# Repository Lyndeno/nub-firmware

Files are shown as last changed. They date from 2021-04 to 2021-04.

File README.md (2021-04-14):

# nub-firmware

Firmware for NUB(Nodal Hub), a long range mesh messaging system. Capstone Project for Electrical Engineering at the University of Alberta.

## Frame Format

### NUB to NUB

| TAG | Message Type | Size of Path | Path | Data Size | Data |
| --- | --- | --- | ---- | --- | ---- |
| ```0x02``` | 1 Byte | 1 Byte | Variable | 2 Bytes | ```Data Size``` Bytes |

### Passing through ATmega

| TAG | Data Len | Message Type | Data Size | Data |
| --- | --- | --- | ---- | --- |
| ```0x02``` | 1 Byte | 1 Byte | 2 Bytes | ```Data Size``` bytes |

### Message Types

| Message Type Byte | Message |
| --- | --- |
| 0x01 | Text Messages |
| 0x02 | Connected/Disconnected phone |
| 0x03 | Adjust NUB Mesh |
| 0x04 | Message Acknowledgement |

## To-Do

- [x] Access point (mostly done)
- [x] Communications with Android app
- [x] UART communication between MCU and ESP8266
- [x] UART communication between MCU and transceiver
- [ ] ~~Power management (Sleep, power button)~~ batteries not allowed for project anymore
- [ ] Status LEDs
- [ ] Serial output? (For debugging)

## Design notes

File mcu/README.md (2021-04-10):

# MCU

The code in this folder is for the main MCU in the NUB. We are using the Atmel ATmega328PB MCU to handle relaying messages between other NUBs and connected Android devices.

## How to Build

This code is developed using Microchip MPLabX with the XC8 compiler. This can be installed on Windows or Linux. If you're using Arch Linux:

``` bash
$ paru -S --needed microchip-mplabx-bin microchip-mplabxc8-bin # Assuming you use paru as an AUR helper
```

You then should be able to just open up this project and compile.

## Design Goals

There are several design goals we want to meet for the best performance:

- [x] Transfer data without variables when possible. We want to ensure there is enough memory for buffers.
- [x] We will have one buffer for each direction of transmission for each connected device.
- [ ] Achieve a 19200 or 115200 baud rate with the long-range transceiver.
- [ ] Achieve a 115200 baud rate with the ESP8266.
- [ ] Protocol to decide when to process what data.
- [ ] Choose a CPU frequency that works at 3.3V, while also achieving the baud rates listed above.
- [x] Buffer sizes that fit in memory, 256 or 512 bytes should be more than enough.

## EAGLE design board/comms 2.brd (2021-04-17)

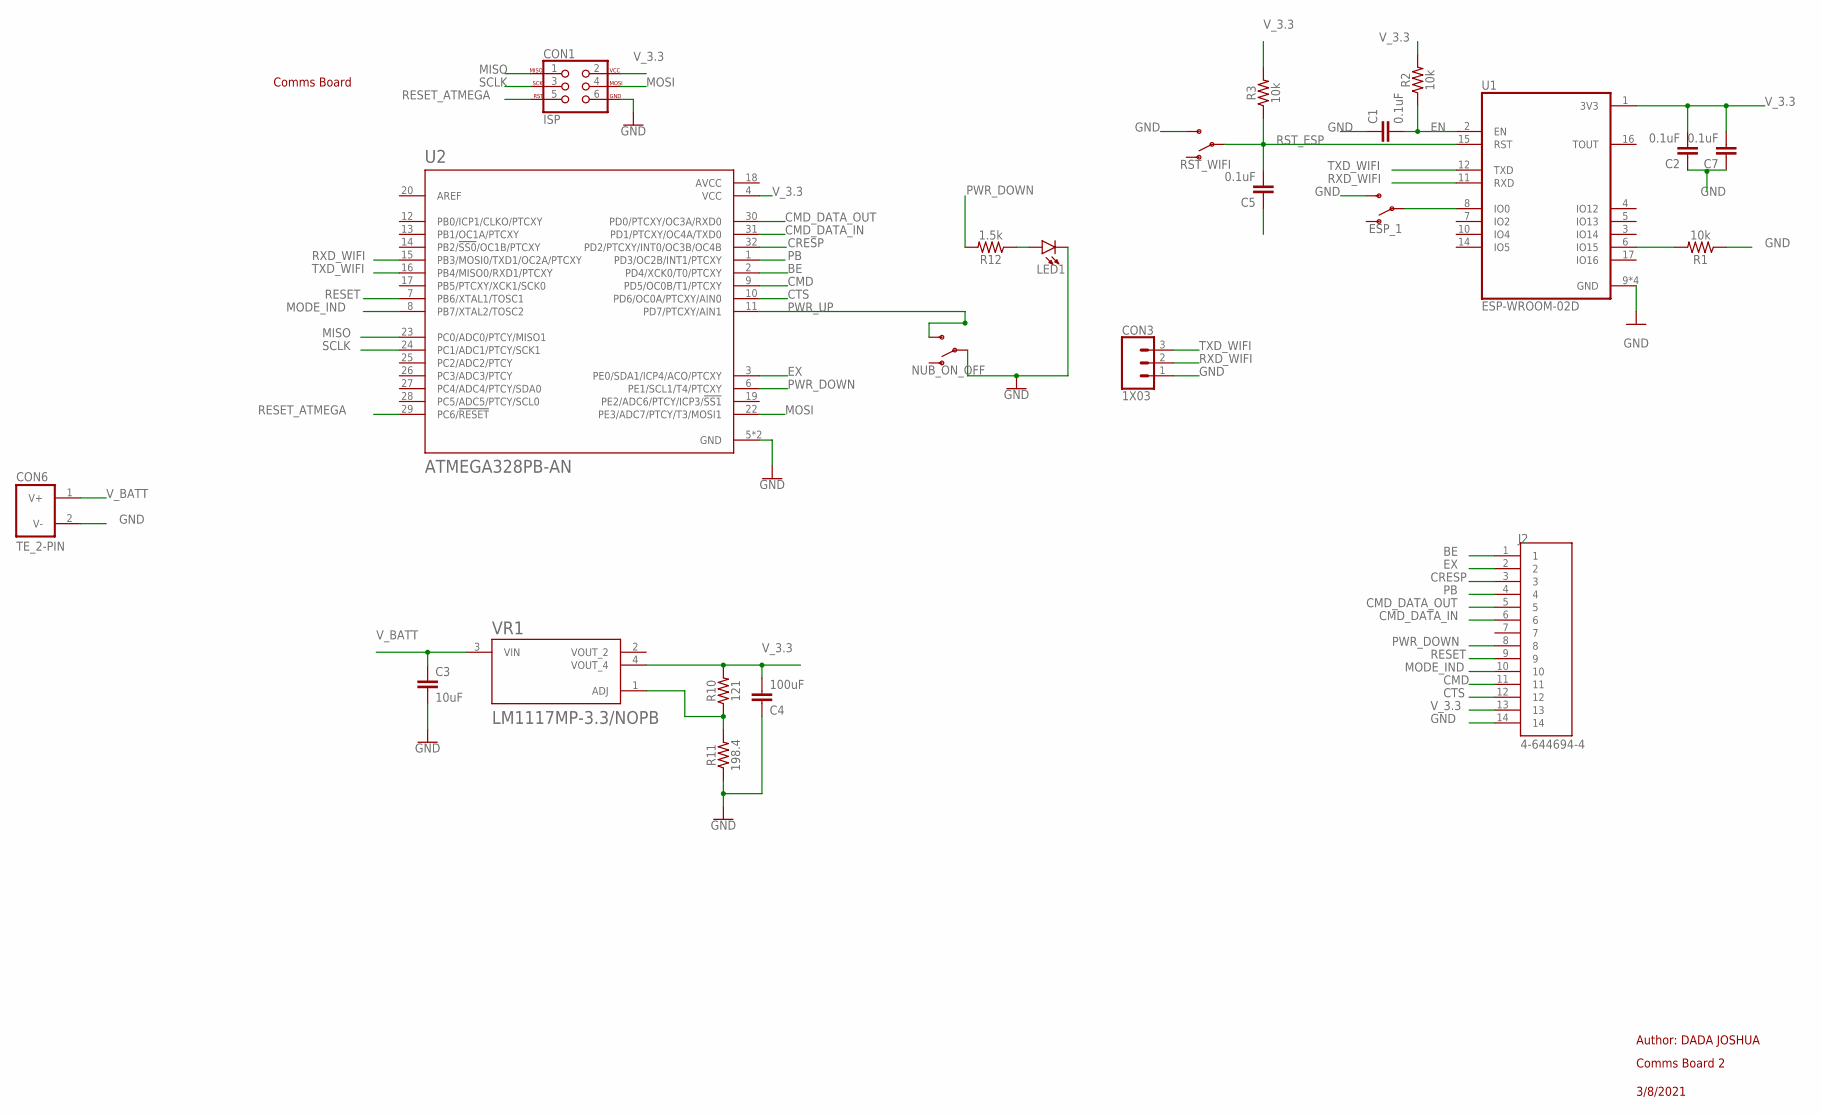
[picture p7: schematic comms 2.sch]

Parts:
C1, C2, C5, C7: 0.1uF; 1210
C3: 10uF; 1210
C4: 100uF; 1210
CON1: ISP; ISP_CONNECTOR
CON3: 1X03
CON6: TE_2-PIN
ESP_1: SWITCH_SPDT
J2: 4-644694-4; TE_4-644694-4
LED1: LED_THROUGH-HOLE
NUB_ON_OFF: SWITCH_SPDT
R1, R2, R3: 10k; 1210
R10: 121; 1210
R11: 198.4; 1210
R12: 1.5k; 1210
RST_WIFI: SWITCH_SPDT
U1: ESP-WROOM-02D; MODULE_ESP-WROOM-02D
U2: ATMEGA328PB-AN; QFP80P900X900X120-32N
VR1: LM1117MP-3.3/NOPB; VREG_LM1117MP-3.3/NOPB

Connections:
AVCC: U2.18 (AVCC)
BE: J2.1, U2.2 (PD4/XCK0/T0/PTCXY)
CMD: J2.11, U2.9 (PD5/OC0B/T1/PTCXY)
CMD_DATA_IN: J2.6, U2.31 (PD1/PTCXY/OC4A/TXD0)
CMD_DATA_OUT: J2.5, U2.30 (PD0/PTCXY/OC3A/RXD0)
CRESP: J2.3, U2.32 (PD2/PTCXY/INT0/OC3B/OC4B)
CTS: J2.12, U2.10 (PD6/OC0A/PTCXY/AIN0)
EN: C1.2, R2.1, U1.2 (EN)
EX: J2.2, U2.3 (PE0/SDA1/ICP4/ACO/PTCXY)
GND: C1.1, C2.1, C3.2, C4.1, C5.1, C7.1, CON1.6, CON3.1, CON6.2 (V-), ESP_1.3 (S), J2.14, LED1.C, NUB_ON_OFF.2, R1.1, R11.1, RST_WIFI.3 (S), U1.9 (GND), U1.13 (GND), U1.18 (GND), U1.19 (GND), U2.5 (GND), U2.21 (GND)
MISO: CON1.1, U2.23 (PC0/ADC0/PTCY/MISO1)
MODE_IND: J2.10, U2.8 (PB7/XTAL2/TOSC2)
MOSI: CON1.4, U2.22 (PE3/ADC7/PTCY/T3/MOSI1)
unnamed: R10.1, R11.2, VR1.1 (ADJ)
unnamed: R1.2, U1.6 (IO15)
unnamed: LED1.A, R12.1
unnamed: ESP_1.2, U1.8 (IO0)
PB: J2.4, U2.1 (PD3/OC2B/INT1/PTCXY)
PWR_DOWN: J2.8, R12.2, U2.6 (PE1/SCL1/T4/PTCXY)
PWR_UP: NUB_ON_OFF.3 (S), U2.11 (PD7/PTCXY/AIN1)
RESET: J2.9, U2.7 (PB6/XTAL1/TOSC1)
RESET_ATMEGA: CON1.5, U2.29 (PC6/!RESET)
RST_ESP: C5.2, R3.1, RST_WIFI.2, U1.15 (RST)
RXD_WIFI: CON3.2, U1.11 (RXD), U2.15 (PB3/MOSI0/TXD1/OC2A/PTCXY)
SCLK: CON1.3, U2.24 (PC1/ADC1/PTCY/SCK1)
TXD_WIFI: CON3.3, U1.12 (TXD), U2.16 (PB4/MISO0/RXD1/PTCXY)
V_3.3: C2.2, C4.2, C7.2, CON1.2, J2.13, R2.2, R3.2, R10.2, U1.1 (3V3), U2.4 (VCC), VR1.4 (VOUT_4)
V_BATT: C3.1, CON6.1 (V+), VR1.3 (VIN)

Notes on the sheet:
Comms Board
Author: DADA JOSHUA
Comms Board 2
3/8/2021

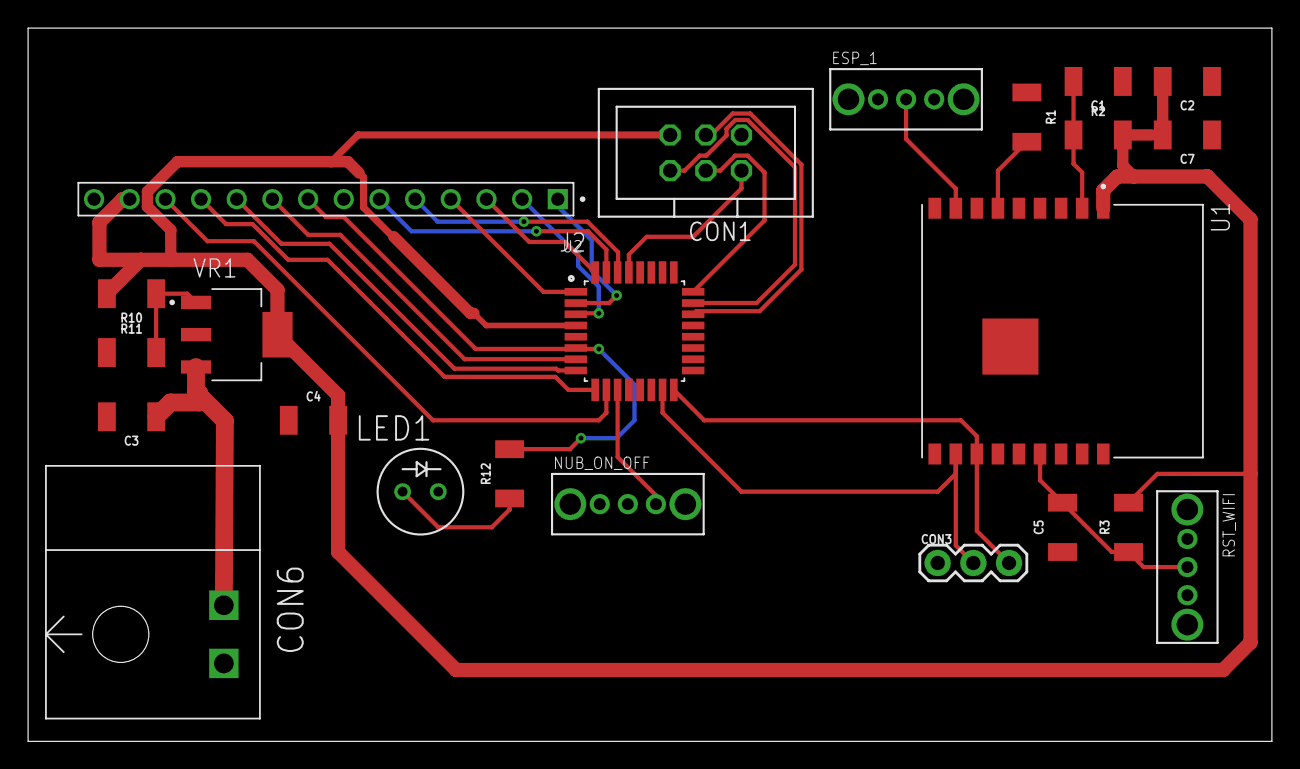
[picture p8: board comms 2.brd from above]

Board: 2 copper layers, 88.6 x 50.8 mm, 23 parts (0 on the bottom side), 27 nets.

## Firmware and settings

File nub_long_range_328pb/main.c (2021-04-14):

/*
 * nub_longrange.c
 *
 * Created: 1/23/2021 3:52:34 PM
 * Author : Kyle Collins
 * Last update: 2021/3/2
 * V1: Added functionality for testing UART coms as a echo
 * Notes:
 
 */ 

#define F_CPU 1000000UL


#include <avr/delay.h>
#include <avr/io.h>
#include <string.h>
#include <stdio.h>
#include <avr/interrupt.h>
#include <stdlib.h>
#include "setup.h"
#include "messaging.h"
#include "handleUart.h"

#define RSTHUM		PORTB6
#define MODEIND		PORTB7

#define CRESP		PORTD2
#define PB			PORTD3
#define CMD			PORTD5
#define SLEEPMODE	PORTD7

#define LED			PORTE1


#define BAUD 9600
#define MYUBRR F_CPU/8/BAUD-1


extern rx0Buffer;

#define RX_BUFFER_SIZE 256
#define TX_BUFFER_SIZE 256

#define MaxNetworkSize 5
#define MAX_NUB_CON 3
#define MAX_PHONE_CON 3

//uint8_t connectedDevices[] = {0x0A, 0x00, 0x12, 0xEF};



// The specific device connections, 35 Bytes
struct localConnections{
	uint8_t deviceDSN[4];
	uint8_t numOfNubCon;
	uint8_t numOfPhoneCon;				// How many devices are connected to this one
	uint8_t nubConnections[MAX_NUB_CON][4];	// The DSN addresses of the connected devices 
	uint8_t phoneConnections[MAX_PHONE_CON][6];	// The mac addresses of connected phones
};



// Overall network structure, 175 Bytes
struct networkStructure{	

	uint8_t numOfDevices;
	struct localConnections device[MaxNetworkSize];		// Max network size of 5 connections 
	
};

struct myConData{
	uint8_t myDSN[4];
	uint8_t myNumOfNubCon;
	uint8_t myNumOfPhoneCon;
	uint8_t myNubConnections[MAX_NUB_CON][4];
	uint8_t myPhoneConnections[MAX_PHONE_CON][6];
};



int main(void)
{
	
	DDRE |= (1 << DDE1);
	PORTE |= (1 << LED);
	USART_setup(MYUBRR);
	sei();		// Enabling interrupts 
	
	
	_delay_ms(100);
	uint8_t *myDSN;
	struct networkStructure *networkPtr, network;
	networkPtr = &network;							// Pointer to network, to be able to transmit through UART
	uint8_t *networkPtr2 = &network;
	struct myConData *myConsptr, myCons;
	myConsptr = &myCons;
	uint16_t networkSize = sizeof(network);
	
	myDSN = setupTransceiver();
	
	
	
	uint8_t value = 0x00;
	for (uint8_t i = 0; i < sizeof(network); i++){
		*(networkPtr2 + i*sizeof(uint8_t))  = value;
	}
	// Mostly test stuff ////////////////////////////////////////////////
	for(int i = 0; i < 4; i++){
		myCons.myDSN[i] = myDSN[i];
		network.device[0].deviceDSN[i] = myDSN[i];
		//network.device[1].deviceDSN[i] = 0x66;
		//network.device[2].deviceDSN[i] = 0x77;
		
		//myCons.myNubConnections[myCons.myNumOfNubCon][i] = network.device[1].deviceDSN[i];
		//network.device[0].nubConnections[0][i] = network.device[1].deviceDSN[i];
		
		//network.device[1].nubConnections[0][i] = network.device[0].deviceDSN[i];	// Connected to this one
		//network.device[1].nubConnections[1][i] = network.device[2].deviceDSN[i];	// Connected to the other one
		
		//network.device[2].nubConnections[0][i] = network.device[1].deviceDSN[i];
		
	}
	
	for(int i = 0; i <6; i++){
		myCons.myPhoneConnections[0][i] = 0x11;	// Just giving it a default value, 
		network.device[0].phoneConnections[0][i] = myCons.myPhoneConnections[0][i];
		//network.device[1].phoneConnections[0][i] = 0x33;
		//network.device[2].phoneConnections[0][i] = 0x44;
	}
	
	
	myConsptr->myNumOfNubCon = 0;
	myCons.myNumOfPhoneCon = 1;
	network.numOfDevices = 1;
	network.device[0].numOfNubCon = myCons.myNumOfNubCon;	
	network.device[0].numOfPhoneCon = myCons.myNumOfPhoneCon;	
	
	//network.device[1].numOfNubCon = 2;
	//network.device[2].numOfNubCon = 1;
	//network.device[0].numOfPhoneCon = 1;
	//network.device[1].numOfPhoneCon = 1;
	//network.device[2].numOfPhoneCon = 1;
	uint8_t output = 0;
	//////////////////////////////////////////////////////////////////
	
	uint8_t firstCon = 1;
	skipBuffer(0);
	
	uint8_t i = 0;
	uint8_t UARTPort;
    while (1){		
		
		if (firstCon == 1){
			
			broadcastCon(0x00,myConsptr);
			
			_delay_ms(7500);
		}
		
		
		if(Bytes0UnRead() > 0){
			UARTPort = 0;
			
			output = handleMessages(UARTPort,networkPtr,networkSize,networkPtr2,myConsptr);
			if (output == 3 || output == 5){
				firstCon = 0;
			}
			
			skipBuffer(0);
		}
		
		if(Bytes1UnRead() > 0){
			UARTPort = 1;
			//TXWrite("AAAAAAAAAAAAAAAAAAAA",20,1);
			//TXWrite(networkPtr,networkSize,1);
			//TXWrite("AAAAAAAAAAAAAAAAAAAA",20,1);
			handleMessages(UARTPort,networkPtr,networkSize,networkPtr2,myConsptr);
			skipBuffer(1);
			
		}
		
		//checkReg();
		//test();
		/* For checking struct
		i++;
		if (i > 100){
			
			TXWrite(networkPtr,sizeof(network),1);
			i = 0;
		}
		*/
		_delay_ms(100);
		
    }
}


void checkReg(){
	
	uint8_t hopTable[4]	= {0xFF,0x02,0x00,0x00};
	uint8_t TXPower[4]	= {0xFF,0x02,0x4D,0x01};		// Setting the power to 25dBm for initial search/ default 
		
	uint8_t UARTBaud[4]	= {0xFF,0x02,0x03,0x02};		// Setting BAUD rate to 19.2 kb/s ( also means this is the transmission speed)
	uint8_t addMode[4]	= {0xFF,0x02,0x4F,0x04};		// Setting address mode as DSN (Volatile address)
	uint8_t showVer[4]	= {0xFF,0x02,0x0A,0x00};		// Do not show version at start up
	uint8_t CMDHold[4]	= {0xFF,0x02,0x6E,0x01};		// If CMD_BAR is low, wait until it goes high to send to mcu
	uint8_t compat[4]	= {0xFF,0x02,0x70,0x00};		// Compatibility mode to enable broadcast function for DSN
	uint8_t autoAdd[4]	= {0xFF,0x02,0x71,0x04};		// Auto addressing for DNS mode
	uint8_t myDSN3[4]	= {0xFF,0x02,0xFE,0x34};				// Read command for preprogrammed DNS values, DSN3 is MSB
	uint8_t myDSN2[4]	= {0xFF,0x02,0xFE,0x35};
	uint8_t myDSN1[4]	= {0xFF,0x02,0xFE,0x36};
	uint8_t myDSN0[4]	= {0xFF,0x02,0xFE,0x37};
	uint8_t LStatus[5]	= {0xFF,0x03,0xFE,0xFE,0x46};	// Status of output lines
	
	PORTD &= ~(1 << PORTD5);	// cmd mode
	
	uint8_t cmds[][4] = {{0xFF,0x02,0xFE,0x4F},		//ADDMODE			0
						{0xFF,0x02,0xFE,0x6B},		//DESNTDSN0			1
						{0xFF,0x02,0xFE,0x70},		//COMPAT			2
						{0xFF,0x02,0xFE,0x4D},		//TX Power			3
						{0xFF,0x02,0xFE,0x4E},		//Baud Rate			4
						{0xFF,0x02,0xFE,0x6E}
						};	
	
	TXWrite(cmds[0],4,0);	
	TXWrite(cmds[1],4,0);
	TXWrite(cmds[2],4,0);					
	TXWrite(cmds[3],4,0);		
	TXWrite(cmds[4],4,0);
	_delay_ms(50);
	
	
	
	
	PORTD |= ~(1 << PORTD5);	// cmd mode
	
}

void test(uint8_t srcDSN){
	uint8_t Add1[] = {0x0A,0x00,0x12,0xEF}; // Left 
	uint8_t Add2[] = {0X0A,0X00,0X12,0XF0}; // Right
	writeDestDSN(Add1);
	
	sendMessageSimple2(Add1,Add2,"HHHHHHHHHH\n",11);
	
}



void sendMessageSimple2(uint8_t srcPhoneAdd[4],uint8_t destPhoneAdd[4], unsigned char msg[],uint8_t msgSize){
	
	
	uint8_t msgType = 0x01;	// message
	
	
	
	
	// Send [msgType (1 byte), deviceNumInPath (1 byte), msgPathSize (1 byte), msgSize (1 byte),
	//       msgPath (var), destination phone address (6 bytes), source phone address (6 bytes), message (var)]
	
	
	writeDestDSN(destPhoneAdd);
	_delay_ms(50);
	
	TXWrite(msg,msgSize,0);			// mac address
	_delay_ms(50);
	
	
	
}



// (struct networkStructure*,uint8_t, uint16_t, struct myConData*,uint8_t
/*
handleMessages(myCons.myDSN,networkPtr,sizeof(network),networkPtr2,myConsptr);
uint8_t updateNetworks(struct networkStructure *network, uint8_t *networkPtr, uint16_t networkSize,struct myConData* myCons, uint8_t newCon)
uint8_t handleMessages(uint8_t *myDSN, struct networkStructure* network, uint16_t sizeOfNetwork, uint8_t *networkPtr, struct myConData* myCons);
uint8_t handleMessages(uint8_t *myDSN, struct networkStructure* network, uint16_t sizeOfNetwork, uint8_t *networkPtr, struct myConData* myCons){
sendToNeighbors = updateNetworks(network,networkPtr,sizeOfNetwork,myCons,newCon);
*/

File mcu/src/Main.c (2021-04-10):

#include "io.h"

#include <stdio.h>
#include <stdlib.h>

#include "comms.h"
#include "buffer.h"
#include "routing.h"


// TODO: Match UART to physical implementation, UART0 and UART1

// IDEA: wifi and transceiver send/receive will probably use very similar code, 
// figure out how to pass UART registers to function

void handle_message(circular_buf * );
void check_frame (circular_buf * );

int main (void) {
    // Initialize buffers first as UART needs them
    init_buffer(&buff_wifi_rx, BUFFER_LENGTH_BYTES);
    init_buffer(&buff_trans_rx, BUFFER_LENGTH_BYTES);
    init_device_table();
    UART_WiFi_init(UBRR_WIFI);
    DDR(PORT_STATUS_LED) |= (1<<PIN_STATUS_LED);
    DDR(PORT_TEST_LED) |= (1<<PIN_TEST_LED);

    while (1) {
        PORT(PORT_STATUS_LED) ^= (1<<PIN_STATUS_LED);

        read_frame(&buff_wifi_rx);
        read_frame(&buff_trans_rx);
        
    }
}

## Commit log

2021-01-15 Updated individual device READMEs
2021-01-25 Add code for turning off usart power reduction
2021-02-04 Add UART receive code
2021-02-15 Ignore vscode arduino config
2021-02-15 Add led blink code to test on-board xplained debugger
2021-02-16 Define UART registers
2021-02-20 More settings for arduino ide
2021-02-23 Test MCU uart output to computer
2021-02-23 Initial RTOS SDK UART output
2021-02-24 Initial circular buffer for UART reception
2021-03-11 Finally got no delay UART reading working
2021-03-11 Switch to redfined registers and create a simple TX function for WiFi UART
2021-03-11 Move frame logic to function for re-use
2021-03-11 Use define for interrupt vector
2021-03-11 Interrupt prototype is unnecessary
2021-03-11 Define tranceiver interrupt vector
2021-03-11 Add formatted documentation and comments. Rename the UART init function to indicate its use for WiFi.
2021-03-11 Add board schematics
    [comms 2.brd, comms 2.sch]
2021-03-11 Added frame data tables
2021-03-18 Define queues and frame type for message routing
2021-03-18 Initialize uart queue
2021-03-19 Add functions to read and write to uart queue, for readability
2021-03-19 Create function for converting messages to bytestream for uart
2021-03-19 Do not need UART event queue at this time
2021-03-19 Fix for loop index definition
    [routing.c]
2021-03-19 Correct queue definitions to uart and not wifi
    [routing.c]
2021-03-19 Define UART RX and TX traffic tasks
2021-03-27 Add ip address to frame data
2021-03-28 Use UART for debug temporarily
2021-03-28 Disable uart for debugging purposes
2021-03-29 Define simple structure for storing connected device information
2021-03-29 Move definition of max wifi devices to header for accessibility
2021-03-30 Initial code for handling the connected device table
2021-03-30 Remove "default" switch cases
2021-03-30 Initial code to queue up device removal on WiFi disconnect
2021-04-02 Handle device frames that handle connect/disconnect
2021-04-02 Handle connection frame in its own function
2021-04-02 Add function prototype for connection frame function
2021-04-02 Add variable names to prototypes for clarity
2021-04-02 launch uart tasks in init
2021-04-02 Use max delay for uart
2021-04-02 Add task prototypes for comms
2021-04-02 Add routing task prototypes
2021-04-02 Message routing from network to UART works
2021-04-02 Change UART TX to use variable-size structures instead of single bytes
2021-04-04 Fix mac index in uart message
    [routing.c]
2021-04-07 Fix esp adding wifi message type to uart when not needed
    [routing.c]
2021-04-08 Correct the message length variable sent over uart
    [routing.c]
2021-04-09 Programmed Disconnect Button to disconnect from the Wifi and return back to Connect page
2021-04-09 Fix attempt on Connect/Disconnect Button to disconnect from the Wifi and return back to Connect page
2021-04-10 Add function to check if device exists in table
2021-04-11 Send message directly to local WiFi device instead of NUB network
2021-04-11 Updated network sharing
    Updated network connection, one unit can now broadcast and have the other until at it to its network list and send it to the first unit for it to have.
    Still some bugs in the code and things to clean up though.
    [handleUart.c, main.c, messaging.c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]
2021-04-11 Added in input from esp UART
    Able to take ESP messages on UART1 and search the NUB for which NUB that phone is connected to and send out that DSN address which will be used for sending messages.
2021-04-13 Move socket to global variable
2021-04-13 When send button is pressed, check if ESP has been notified of presence and if not then notify ESP
2021-04-13 Move packet reception to own thread so messages can be received all the time
2021-04-17 Update board files
    [comms 2.brd, comms 2.sch]

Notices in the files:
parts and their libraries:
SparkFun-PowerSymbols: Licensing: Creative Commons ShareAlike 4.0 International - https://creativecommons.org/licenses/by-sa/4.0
